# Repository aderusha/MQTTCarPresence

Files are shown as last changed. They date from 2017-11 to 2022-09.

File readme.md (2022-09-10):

# MQTTCarPresense

This project utilizes a [WeMos D1 mini Pro](https://wiki.wemos.cc/products:d1:d1_mini_pro), u.FL to SMA antenna whip, and an external antenna in a 3D-printed enclosure to indicate presense when powered on and attached to MQTT.

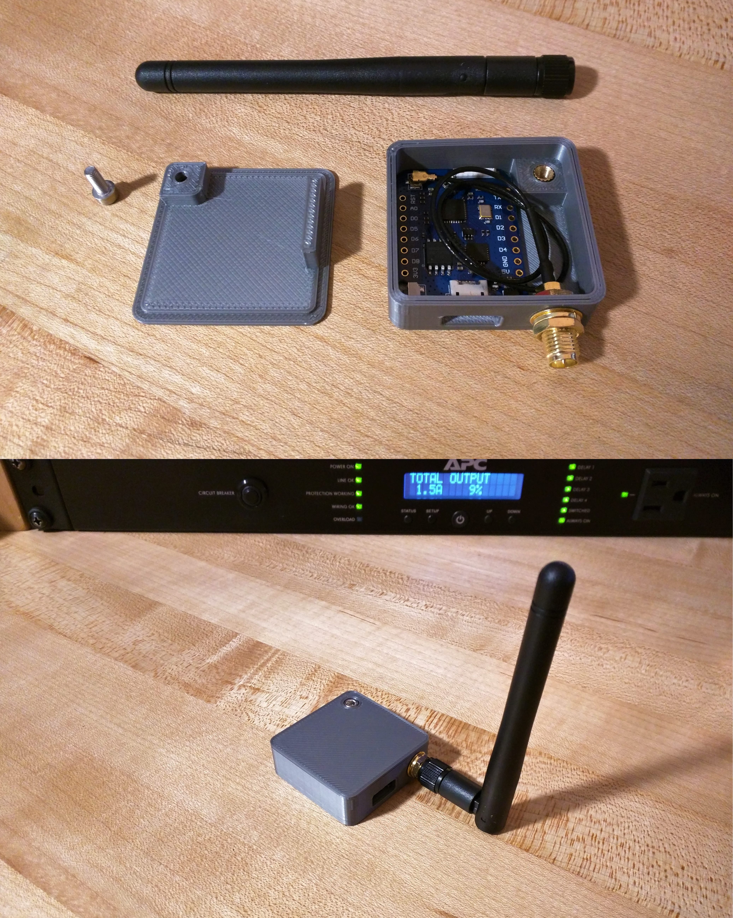
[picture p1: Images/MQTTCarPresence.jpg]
MQTTCarPresense


[The included Arduino code](/MQTTCarPresence) is setup to work with [Home Assistant MQTT Discovery](https://home-assistant.io/docs/mqtt/discovery/) to automatically create a `binary_sensor` device which will indicate the connection status of the device.  The device should be powered from your car's ignition so it's only on when the car is running.  When the device powers on, it will attempt to connect to the defined MQTT broker, publishes a discovery message, and configures a Last Will and Testament.  When the device is powered off (or you drive out of WiFi range), the Last Will and Testament is sent by your broker to update subscribed automation system(s).

[The included Home Assistant blueprint automation](MQTTCarPresence.yaml) example utilizes this information to open or close a connected garage door. Just copy the file url into the blueprint import menu and create an automation using the blueprint!



## Workflow - User perspective

* Car is in your garage and the garage door is closed
* You get in the car and turn it on, the garage door opens
* You drive away, the garage door closes a minute later
* When you arrive back home, the garage door opens as you approach
* When you turn off your car, the garage door closes about a minute later

## Detailed workflow

* Car is powered off, garage door is closed
* Car turns on, device publishes connection message to MQTT
* Home automation platform sees that the garage door is closed and the device is connected, then sends command to open garage
* You drive away when ready
* Device eventually drives out of range, dropping connection with the broker
* MQTT broker sends disconnection message configured as the LWT
* Home automation platform sees the garage door is open and the device has disconnected, then sends command to close garage
* You go on about your day, then return home.
* Device connects to WiFi, then MQTT and publishes connection message
* Home automation platform sees that the garage door is closed and the device is connected, then sends command to open garage
* You park your car and turn it off, dropping connection with the broker
* MQTT broker sends disconnection message configured as the LWT
* Home automation platform sees the garage door is open and the device has disconnected, then sends command to close garage

## Bill of Materials

* [WeMos D1 mini Pro](https://wiki.wemos.cc/products:d1:d1_mini_pro)
* u.FL to SMA antenna whip
* External 2.4GHz WiFi antenna
* M3x8mm socket head cap screw (or similar)
* M3x4x6 threaded insert (or similar)

## Arduino programming

The first order of business will be to setup the Arduino IDE to flash the provided Arduino sketch to the ESP8266.  [Download the IDE for your platform](https://www.arduino.cc/en/Main/Software) and [follow these instructions to add support for the ESP8266 platform](https://github.com/esp8266/Arduino#installing-with-boards-manager).

Next you will need to add the PubSubClient library for MQTT.  [Follow this guide for the general process](https://www.arduino.cc/en/Guide/Libraries) and add the 'PubSubClient' from the Library Manager.

[At the top of the Arduino sketch are several fields you must modify to fit your environment](https://github.com/aderusha/MQTTCarPresence/blob/master/MQTTCarPresence/MQTTCarPresence.ino#L3-L10) (WiFi details, MQTT broker IP, node name, etc).  Once those fields have been set you can upload to your microcontroller and monitor sensor status in Home Assistant.

> ## WARNING:
> 
> If you will be deploying more than one of these devices you **must** change the node names to be unique.  Failure to do so will result in a cascading series of MQTT connections/disconnections as your devices compete for access to your broker.

## WeMos D1 Mini Pro Antenna

In order to utilize an external antenna on the WeMos D1 Mini Pro, you will need to move a 0 ohm 0603 SMT resistor.  See [this blog post](http://raspi.tv/2017/how-to-use-external-antenna-on-wemos-d1-mini-pro-surface-mount-rework-video) along with [an accompanying video](https://www.youtube.com/watch?v=3lHoG1mu7hY&t=72) on how to make that happen.  A hot-air station will make this easier, but I was able to do this with a normal pencil iron.

## Tasmota Firmware Variant

If you are more familiar to Tasmota flashing and usage rather than Arduino Programming and building, this is another variant that you could use.  It will replace the **Arduino Programming** section above, but follows the guidelines of just about everything else.  The blueprint that is attached to this project named MQTT_Tasmota_CarPresence.yaml can be used as an alternate along with flashing the Di-Mini with Tasmota to accomplish the same thing as the original.  

This Tasmota Variant is set-up to work with [Home Assistant Tasmota Integration](https://www.home-assistant.io/integrations/tasmota/) to automatically create a `switch` which will indicate the connection status of the Car Presence Device.  It should show up as a switch with a name that matches the FriendlyName set-up in the Tasmota Web Console.

####    Follow these steps to flash the D1 Mini if using Tasmota: ####

* Flash the D1 Mini to the latest Tasmota version.
* Set up your WIFI, MQTT, Hostname, Friendly name, and all the normal stuff.  Details on the Tasmota homepage.
* Set the Device module to type `generic(18)`.
* Under configure module, 
    * set GPIO2 as LEDi 1
    * set GPIO4 as Button 1
    * set GPIO5 as Relay 1
* On the console, paste this to set-up the mcu functions as required for proper operation (Check Tasmota website for details on what these are):  
    * ```Backlog  SO19 0; SO56 1; SO63 1; SO65 1; WifiConfig 5```
* Go to Configure Other and be sure to set a Web Admin Password in case it goes into AP mode when you are away from Home.
* Set-up the blueprint `MQTT_Tasmota_CarPresence.yaml` similar to the instructions for the other blueprint above.



## Buy me a coffee

Buy me a coffee (https://www.buymeacoffee.com/gW5rPpsKR)

This project is powered by coffee.  [I might get a little weird about it at times](https://github.com/aderusha/RoastLearner), but it's not much of a stretch to suggest that coffee both powers and consumes a fair portion of my mental energy.  [Hook me up if you think HASP is cool](https://www.buymeacoffee.com/gW5rPpsKR).  Thanks!

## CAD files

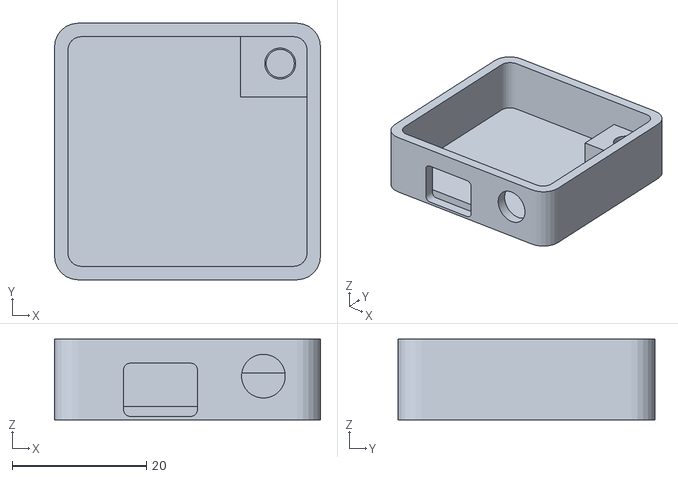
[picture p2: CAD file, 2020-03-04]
WeMos Pro Mini enclosure bottom.stl
39.6 x 38.2 x 12.0

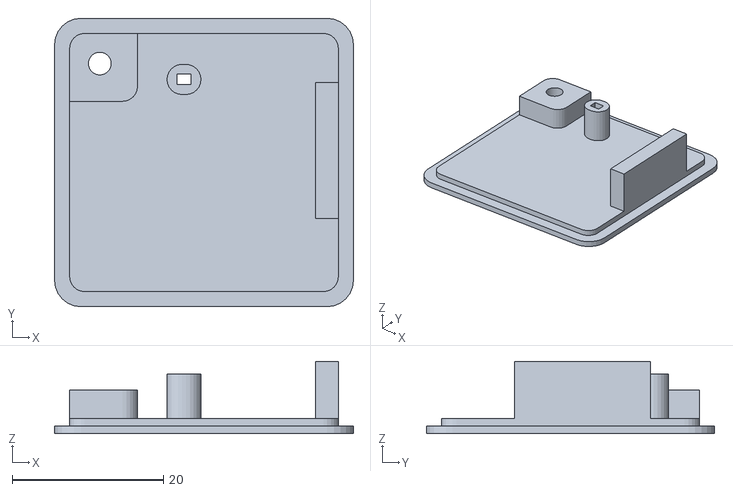
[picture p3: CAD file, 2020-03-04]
WeMos Pro Mini enclosure top.stl
39.6 x 38.2 x 9.60

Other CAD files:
WeMos Pro Mini enclosure.skp

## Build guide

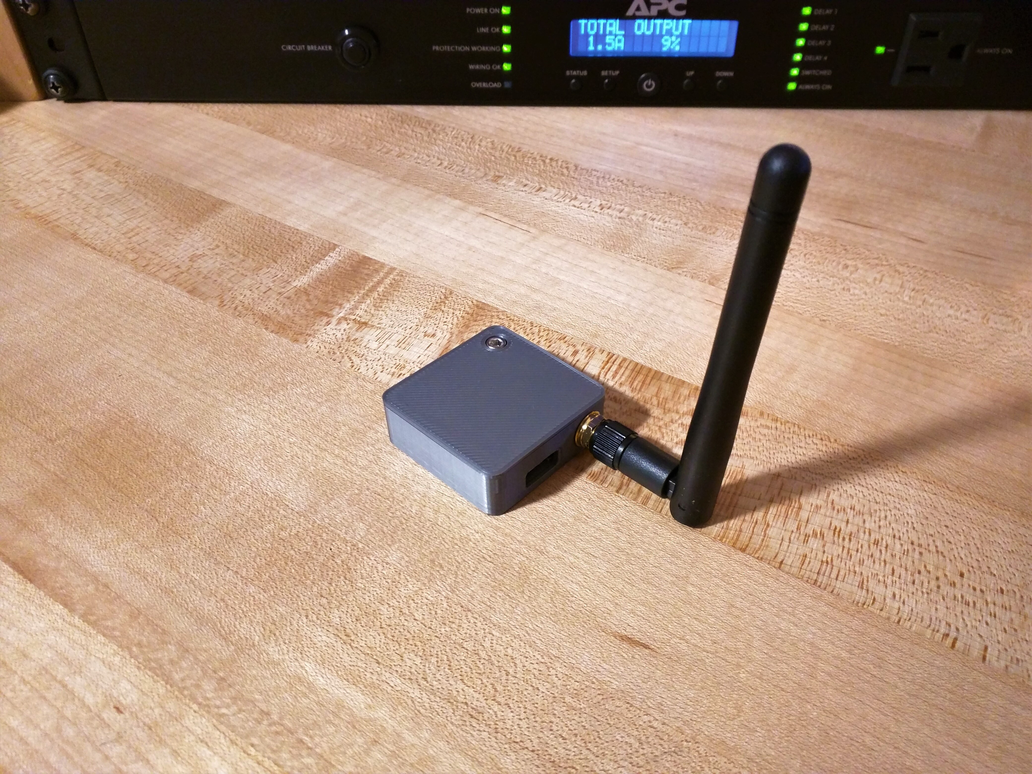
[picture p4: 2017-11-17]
Images/Assembled.jpg

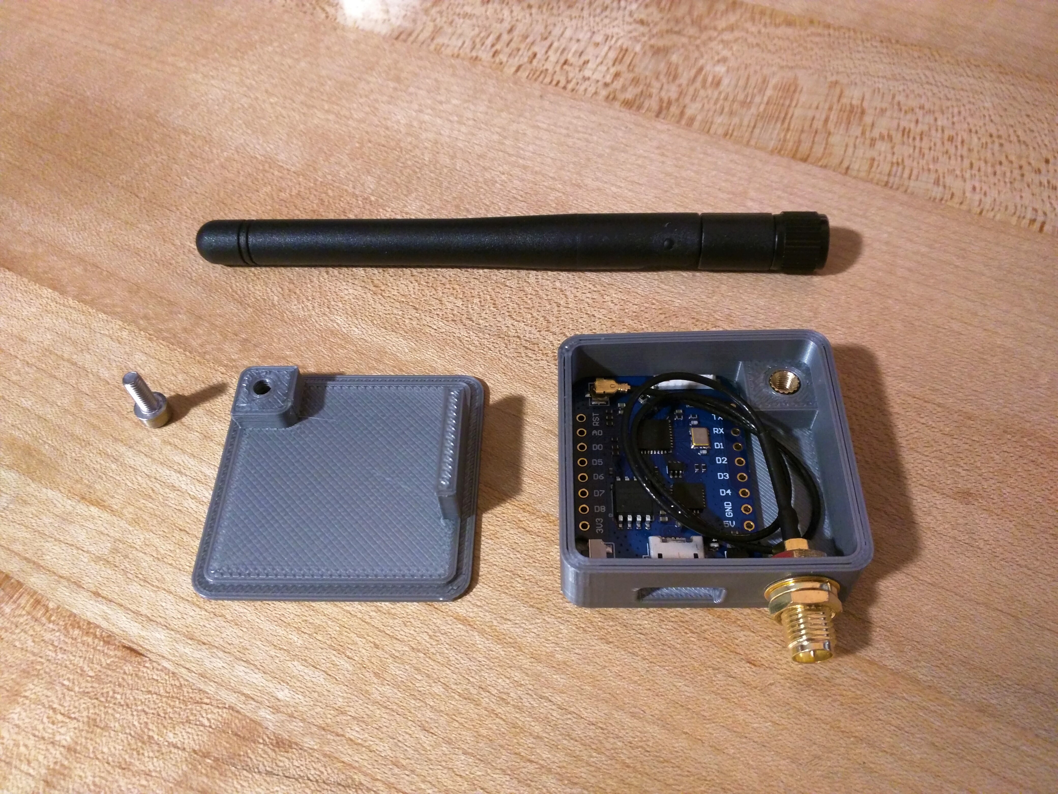
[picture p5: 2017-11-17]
Images/Disassembled.jpg

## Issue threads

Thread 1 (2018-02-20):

Will this work with D1 mini (non-pro)?

Snipercaine, 2018-02-20:
Hi,
Love this project.  I just tried it today and so far haven't been able to get it working.  I'm using a non-pro D1 mini.  I wouldn't expect that to be the problem.
I modified the values at the top of the sketch with my info. The max packet size is 512. The sketch loads up fine without any errors.
In Home Assistant I added the automation. Changed the entity_id to match the mqttNode (I assumed that was necessary, maybe it isn't).  When I power up the D1 mini, I don't see a new binary_sensor appear.
Most concerning is that when I plug the D1 into the computer, I don't see anything coming up in the Serial Monitor.

Any ideas of something else I can try?
Thanks!

aderusha, 2018-02-20:
This for sure will work on the non-pro mini (however the STL for the case may not work).  Serial for sure should be working @ 115200 8N1, so double check that the serial device is being created on your computer when plugging in the D1 mini and confirm you can get serial data to display.  From there you should be able to view debug messages regarding connection to WiFi and MQTT.  Next, use an MQTT client to make sure that the device is successfully publishing messages to your broker.  Finally, confirm that Home Assistant MQTT Discovery has been enabled in your `configuration.yaml` so that the `binary_sensor` device can be auto-created.

Snipercaine, 2018-02-21:
Thanks for the quick response!
I got it working.  I didn't have the mqtt discovery loaded.
I also did the automation in the automation editor.

I'd like to make a how-to video for this project.  I'll give you all the credit.
You can see the other stuff I've done here:  YouTube.com/c/DrZzs

Good work on this!  Genius idea!
Thanks
-Justin

ericflores, 2018-02-23:
As an alternative, I flashed Tasmota binary into the wemos using the flashing executable (Windows) that comes in the Espeasy zip file. Then configured following the instructions in the Tasmota wiki.
It is working perfectly.

Yet, I would like to capture uptime in minutes or seconds, and Tasmota only provides hours.

When I leave home I need the gate to close quickly after disconnecting, but when arriving I need some time to step out of the car and exit the garage thru the gate. I know that if the Wemos have been up more than 5 minutes is because I'm arriving. I could setup Homeassistant to behave differently when I'm leaving based on uptime.

ericflores, 2018-02-23:
Ohh, I had not even read your code. Your are reporting uptime in milliseconds! Looks like I'll have to compile and install your code!

edif30, 2018-05-03:
Will a NodeMCU board work?

1043717432, 2018-05-04:
Thanks for sharing

gorinie, 2018-05-20:
Hi
It is working form me with an ESP-01 and an USB adapter for ESP-01. This is very useful, you just plug it in the usb port on your car. No additional antenna but a Wemos d1 Mini with [(https://github.com/martin-ger/esp_wifi_repeater)] to repeat the signal nearby the Garage Door.  Also my automation in Home Assistant make use of a threshold on the signal with a binary_sensor, in such a way one can trim the closing of the Garage with [https://github.com/marthoc/GarHAge]  even before disconnection (this requires tuning...)

yaml code for Home Assistant
```
binary_sensor:
 - platform: threshold
    entity_id: sensor.yarissignal
    lower: -85.0
    name: yaris-threshold
    friendly_name: Yaris Threshold
    hysteresis: 0.0
```

regards,
Edoardo

1043717432, 2018-05-25:
@gorinie  Hi, Hello, thanks for sharing. What kind of esp-01 do you use with USB interface?

gorinie, 2018-05-25:
Hi,
I bought on amazon these:

https://www.amazon.it/AZDelivery-Adattatore-ESP-01-Modulo-Arduino/dp/B078J7LDLY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

Zoltant7, 2018-09-14:
This is  fun project, but i rather use HA with discovery feature so i only need my phone to detect that I'm home or not!

gorinie, 2018-09-14:
Did you try to convert your project in [esphomeyaml](https://esphomelib.com/esphomeyaml/) ? would be quite useful....

Closed 2020-01-15.

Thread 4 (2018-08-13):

Home Assistant not discovering D1 Mini Pro

FutureTense, 2018-08-13:
I’m using [this Aideepen WEMOS D1 Mini Pro - 16M Bytes External Antenna Connector ESP8266 WIFI IoT Board](https://www.amazon.com/dp/B07333L9VR/ref=cm_sw_r_cp_tai_WiqCBb5H7C2W1) but Home Assistant is not discovering it.  I know it’s connecting to my WiFi, because my router shows it and I can ping it.

What can I do to debug this?

aderusha, 2018-08-13:
Check to confirm that [Home Assistant MQTT Discovery](https://www.home-assistant.io/docs/mqtt/discovery/) is enabled, and try monitoring your MQTT broker messages using MQTT Lens (or similar) to make sure the device is sending messages.

neirbomn, 2019-01-16:
@aderusha,
I'm having considerable trouble getting this project to work. It's a fabulous idea and if I can get it to work it will be even better!

The binary_sensor 'CarPresence' and uptime and signal sensors are being created so MQTT discovery is definitely on.
I've also used MQTT Lens to check topics are being sent. They are as shown by a power cycle of the Wemos D1 Mini Pro in the screenshot below but I think my automation or HomeAssistant is where the problem lies for me.
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
In HomeAssistant, the binary sensor is shown all in lower case in the states section of the UI.
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

I altered the automations.yaml file entry for this but it doesn't seem to work. Any ideas appreciated - I've just about given up for the time being as I've spent 3 days trying to get it to work.

I have tried renaming the mqttNode in lowercase, this appears to either cause a conflict and the binary_sensor is repeatedly kicked off the MQTT server, setting the binary_sensor to OFF, it then reconnects which causes the binary_sensor to be set to ON and so on... I think this is if the 'CarPresence' binary_sensor is still in the config or if I send empty payloads and remove the 'CarPresence' sensors, update and reflash the WEMOS and also clear out MosQuiTTo's db and I check for the topic "homeassistant/binary_sensor/carpresence/state" then nothing is sent.

Is there anything you can think of checking or suggest?

aderusha, 2019-01-16:
Can you share your automation?

Closed 2020-01-15.

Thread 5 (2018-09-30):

New Binary sensor not being created

madzur, 2018-09-30:
Hello Aderusha and all. I love this idea and would really like to get this one working. I saw Dr. ZzS video and write up, which led me to this Github page.
I followed Aderusha's instructions with some help from Dr. ZzS more detailed steps and managed to set up Home assistant MQTT discovery and load Aderusha's sketch onto a D1 mini. The trouble starts when I plug the D1 mini into power and it connects to my wifi. I can see it in HA MQTT log as connected, however it is not adding itself as a binary sensor to configuration.yaml

> 1538340853: New connection from 192.168.1.160 on port 1883.
1538340853: New client connected from 192.168.1.160 as CarPresence (c1, k15, u'').

Specifically, in Dr. ZzS writeup (here: http://drzzs.com/mqtt-car-presence/) I’m stuck at the following step:

> After that, restart Home Assistant and plug in your D1 Mini. After a few seconds the blue LED will start flashing like crazy. This sketch is genius. It adds itself as an entity to Home Assistant.  Go to your states page and you should see a new “binary_sensor.CarPresence”.  Once you see that, you’re ready for the next step.

However the binary_sensor never shows up, either in configuration.yaml or in the states. Any tips on what I can do?

madzur, 2018-10-04:
I managed to get the serial monitor working and it is showing me the following output:
`
SDK:2.2.1(cfd48f3)/Core:2.4.2/lwIP:2.0.3(STABLE-2_0_3_RELEASE/glue:arduino-2.4.1-13-g163bb82)/BearSSL:6d1cefc

Hardware initialized, starting program load
Connecting to WiFi network: XXXXscandone
scandone
state: 0 -> 2 (b0)
state: 2 -> 3 (0)
state: 3 -> 5 (10)
add 0
aid 7
cnt

connected with XXXX, channel 11
dhcp client start...
ip:192.168.1.160,mask:255.255.255.0,gw:192.168.1.1
.
WiFi connected successfully and assigned IP: 192.168.1.160
Initialization complete

Attempting MQTT connection to broker: 192.168.1.101
MQTT discovery connectivity config: [homeassistant/binary_sensor/CarPresence/config] : [{"name": "CarPresence", "device_class": "connectivity", "state_topic": "homeassistant/binary_sensor/CarPresence/state"}]
MQTT discovery connectivity state: [homeassistant/binary_sensor/CarPresence/state] : [ON]
MQTT discovery signal config: [homeassistant/sensor/CarPresence-signal/config] : [{"name": "CarPresence-signal", "state_topic": "homeassistant/sensor/CarPresence-signal/state", "unit_of_measurement": "dBm", "value_template": "{{ value }}"}]
MQTT discovery signal state: [homeassistant/sensor/CarPresence-signal/state] : -56
MQTT discovery uptime config: [homeassistant/sensor/CarPresence-uptime/config] : [{"name": "CarPresence-uptime", "state_topic": "homeassistant/sensor/CarPresence-uptime/state", "unit_of_measurement": "msec", "value_template": "{{ value }}"}]
MQTT discovery uptime state: [homeassistant/sensor/CarPresence-uptime/state] : 20831
MQTT connected
pm open,type:2 0`

Still, when I check the states item in Home assistant, no new binary sensors appear. I’m out of my depth here, so any tips would be greatly appreciated.

aderusha, 2018-10-12:
Excellent, thanks for posting and tracking this down!

Closed 2018-10-12.

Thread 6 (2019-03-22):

Use this without the HASS automatic detection

Hyukishi, 2019-03-22:
Is there any chance you could rewrite a portion of this that would NOT utilize the automatic discovery of HASS? I want to be able to test the MQTT functionality without having to rely on HASS to pick up the device in order to be used and simply using the MQTT broker, in my case mosquitto, instead.

Villhellm, 2019-03-22:
You can subscribe to the topics manually as well. The topics are all listed in the ino file.

aderusha, 2019-03-23:
@Villhellm has it correct - the auto discovery is just there to help if you want to use it, there's nothing saying you must do so.  If you want to manually create an MQTT sensor, or use this with OpenHAB, or whatever else you're looking to do, you can do so without modifying any code in this project.  Just watch the MQTT messages, and configure your automations to react as needed.

Hyukishi, 2019-03-23:
Thanks to both of you. Have a good weekend!

Closed 2019-03-23.

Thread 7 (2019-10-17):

Wemos D1 Mini Pro - Failed to connect to ESP8266

biiiink, 2019-10-17:
I get this error when trying to upload this sketch to a D1 Mini Pro:

`Arduino: 1.8.10 (Mac OS X), Board: "LOLIN(WEMOS) D1 mini Pro, 80 MHz, Flash, Disabled, All SSL ciphers (most compatible), 16M (15M SPIFFS), v2 Lower Memory, Disabled, None, Only Sketch, 115200"

Sketch uses 312248 bytes (29%) of program storage space. Maximum is 1044464 bytes.
Global variables use 29952 bytes (36%) of dynamic memory, leaving 51968 bytes for local variables. Maximum is 81920 bytes.
esptool.py v2.6
2.6
esptool.py v2.6
Serial port /dev/cu.usbserial-01849A42
Connecting........_____....._____....._____....._____....._____....._____.....____Traceback (most recent call last):
  File "/Users/biiiink/Library/Arduino15/packages/esp8266/hardware/esp8266/2.5.2/tools/upload.py", line 25, in <module>
    esptool.main(fakeargs)
  File "/Users/biiiink/Library/Arduino15/packages/esp8266/hardware/esp8266/2.5.2/tools/esptool/esptool.py", line 2653, in main
    esp.connect(args.before)
  File "/Users/biiiink/Library/Arduino15/packages/esp8266/hardware/esp8266/2.5.2/tools/esptool/esptool.py", line 468, in connect
    raise FatalError('Failed to connect to %s: %s' % (self.CHIP_NAME, last_error))
esptool.FatalError: Failed to connect to ESP8266: Timed out waiting for packet header
esptool.FatalError: Failed to connect to ESP8266: Timed out waiting for packet header`

I have tried using a D1 Mini and it worked fine.  I've also tried a different D1 Mini Pro
These are the settings im using for the D1 Mini Pro
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

Any help would be greatly appreciated

aderusha, 2019-10-17:
This error is related to the communication between your Mac and the serial interface on your WeMos D1 Mini Pro.  It could be a bad board, bad cabling, or software configuration.  You might want to check [the issues list for esptool](https://github.com/espressif/esptool/issues) for further troubleshooting help.

Closed 2020-01-15.

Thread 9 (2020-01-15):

MQTT Retain

broyuken, 2020-01-15:
Hello,

I have this set up and working and LOVE it, it works great. The only issue I have is that when I restart HA the sensor state goes into unknown until I start the car again. How would I go about setting the retain flag or similar to make HA remember its last state upon a restart?

aderusha, 2020-01-15:
If you check out lines [152-157](https://github.com/aderusha/MQTTCarPresence/blob/master/MQTTCarPresence/MQTTCarPresence.ino#L152-L157) you'll find a group of commands to publish configuration and state to MQTT.  [The publish() function](https://pubsubclient.knolleary.net/api.html#publish2) accepts an optional third parameter for setting the retain flag.  Add a `, true` to the end of the function calls which don't already have that, and those additional published messages will also be retained.

broyuken, 2020-01-23:
Finally got a chance to try it, it worked perfect! Thank you

broyuken, 2020-01-23:
One thing I've noticed is that throughout the day when the car is off, the RSSI signal strength changes significantly. Any idea why this might be happening? The car is sitting in the garage off and it goes from -50 to -70. This throws off my card that shows if the car is in the garage or if it's away,

aderusha, 2020-01-23:
It's simply reporting the value provided to it by the ESP8266.  You're talking about a radio that was sold for a dollar, so adjust your expectations about the stability of that number accordingly.

If you wanted, one could possibly add a filtering library to smooth out the values over time with the hope of possibly removing noise from the signal.  This might be a good starting point: https://github.com/denyssene/SimpleKalmanFilter

broyuken, 2020-01-24:
That’s not what I’m talking about though. If I pull into my garage at 9am, and the RSSI is -50. I shut the car off and don’t get in it again that day. Around 11 or 12 the RSSI changes to -70. Note that the ESP has not turned on since 9am. This only started occurring since I enabled the retain flag on those 3 lines.

aderusha, 2020-01-24:
In that case something is publishing that value.  Try logging MQTT messages on your broker and see if you can't find what sent that value over.

broyuken, 2020-01-24:
Ok, I'll try to check my mosquitto logs

broyuken, 2020-02-18:
I checked mqtt explorer and it's retaining a value of -44 even though when my wife left for work this morning it had a value of -78. So when I restart HA it thinks my car is in the garage, when in fact it's gone. Something about the message isn't being retained correctly, any ideas? Either it's not updating to a new retained value or something.

aderusha, 2020-02-18:
Is there any chance one or more devices might have retain on, while another doesn't?  This should be trackable if you leave MQTT Explorer running and check the message history.

broyuken, 2020-02-18:
I'm not sure I follow, I have 2 cars I track with this, one has retain on (Odyssey), the other one I haven't updated yet (Murano). I wanted to fix this one first. Both devices have separate names, so they should be 2 separate entities.

aderusha, 2020-02-18:
Just throwing out ideas as to what might be happening there on your network, thought being maybe you have two devices publishing on the same topic but one of them isn't retaining for whatever reason.

I'd recommend keeping a copy of MQTT Explorer open (or similar), and using that to try and catch the problem in the act.  Those messages are there because something sent them, so it seems like the next step is to try and figure out what that was and then why.

broyuken, 2020-02-18:
So my wife just got home, the signal was set to -49, I restarted HA and now it's set to-64. However mqtt explorer is still showing -49. No idea where it's getting these numbers from.

kbweathe, 2020-03-03:
I just completed this project.  How can I make my garage door close as soon as I turn off the ignition. I have checked my automation in HA and I don't have a delay set.  Is the delay in the last will and testament?  If so how do I change it.  Help would be appreciated.

aderusha, 2020-03-03:
The LWT timeout is set by the "keepalive" value, which you can change in the pubsubclient.h file.  You can find details about this [here](https://github.com/knolleary/pubsubclient#limitations) and you can see the `#define` for that [here](https://github.com/knolleary/pubsubclient/blob/master/src/PubSubClient.h#L31).

Setting this value below 15sec is probably a bad idea, but that's where you'd do it.

kbweathe, 2020-03-03:
Allen,
I found the file but will take your advice and leave it at 15 sec.  Thanks so much for your help and quick response!  I have wanted to do this for 20+ years.  I also have a sliding gate that I am controlling with your project. I would like to send you some money for a couple of coffees, Cokes, or what ever you do. Can I do that for you? PayPal?  Let me know how and where, if you would accept it. I thank the good Lord for smart people like you so willing to share and help!
Brent 

    On Tuesday, March 3, 2020, 7:26:08 AM CST, Allen Derusha <notifications@github.com> wrote:

The LWT timeout is set by the "keepalive" value, which you can change in the pubsubclient.h file. You can find details about this here and you can see the #define for that here.

Setting this value below 15sec is probably a bad idea, but that's where you'd do it.

—
You are receiving this because you commented.
Reply to this email directly, view it on GitHub, or unsubscribe.

aderusha, 2020-03-04:
> Allen, I found the file but will take your advice and leave it at 15 sec.  Thanks so much for your help and quick response! 

You're welcome!

> I have wanted to do this for 20+ years.  I also have a sliding gate that I am controlling with your project. I would like to send you some money for a couple of coffees, Cokes, or what ever you do. Can I do that for you? PayPal?  Let me know how and where, if you would accept it.

I've added my [Buy Me a Coffee link](https://www.buymeacoffee.com/gW5rPpsKR) to the project page, thanks in advance for the consideration, I really appreciate it!

broyuken, 2020-08-18:
Curious, what is the reason against changing this setting? Would it just be if the car loses wifi while backing in the door could start closing on the roof? I was thinking of changing it to 5 seconds, wondering if this would be a fairly safe compromise?

aderusha, 2020-08-18:
That, and also because WiFi can be spotty, particularly when there is a $1 device with a PCB antenna involved.  So if for whatever reason it goes offline for a few seconds, just the time for the reconnect alone will trip over your 5 second window.  Leave some room for error, particularly when dealing with large mechanical systems.

broyuken, 2020-08-18:
I didn't even think of the time to boot, that makes a lot of sense. I will keep it at 15 seconds, thanks.

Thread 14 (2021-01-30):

Question disconnect time

03397, 2021-01-30:
Is there a way to make the displayed as disconnected earlier?

It takes sometime after I am disconnected from the wifi network to turn the binary sensor to off.

It does not happen the same when I am connected.

aderusha, 2021-01-30:
The keepalive interval is 10 seconds and should result in something around 30-60 seconds before the system knows the device is offline.  You don't want that number much lower because any intermittent dropped packets can result in the door trying to close on top of your car.

03397, 2021-01-30:
Is this configurable on the code?
To be honest with you I could not find it.

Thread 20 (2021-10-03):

Tasmota Variant won't work if relay is turned off.

SirGoodenough, 2021-10-03:
If you watched the DrZzs stream today, we found a bug in the Tasmota code...
I didn't find this in testing or think of it, but the relay needs to be ON for this to work correctly.
It monitors the switch for ON or unavailable...
Just need to add this to the config on the car D1 Mini.  I can't fix the repo until i get back home because my GitHub editing computer is there, but add this to the car's Tasmota set-up and it will always be started up in the on state when the device turns on.
```text
PowerOnState 1
so63 1
```
I will be able to update this at the end of October, until then, this is a note to make sure this problem gets fixed.

I will be happy to fix it then.

In the mean time, leave the relay set to on and it will continue to work as shown in the repo.

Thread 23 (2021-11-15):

Can the Arduino code be changed over the air?

VictorMFCoelho, 2021-11-15:
Hi!
My D1 Mini is on a hard to reach spot, can it be accessed over the air?
I have to make changes on two devices, one I have to clear the credencials as the car will be sold and the other a have to change the node name. Can it be done over the air?
Thanks!

aderusha, 2021-11-15:
Kinda yes but probably no.  If you compiled the code yourself and set the [otaPassword](https://github.com/aderusha/MQTTCarPresence/blob/master/MQTTCarPresence/MQTTCarPresence.ino#L5), then yes you can use the arduino Over-The-Air flash update mechanism to flash the device.  If you didn't set this value at compile time, you'll need physical access to the device.

VictorMFCoelho, 2021-11-15:
Thanks a lot!

Closed 2021-11-15.

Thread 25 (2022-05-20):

Wifi not working

Gurgeh88, 2022-05-20:
Hi there,

I've followed the steps in the readme and double checked the wifi settings that I entered into the sketch but after I've finished setting everything up and get to the stage for testing, nothing happens.

The LED does not blink like crazy, I can't ping the device from a local computer (destination host unreachable) and no new entity shows up in Home Assistant. I know the MAC address of the board so I have assigned it an IP in my router. Using the MQTTCarPresence sketch, it's not showing up as connected at all.

I double checked that the board was actually working on Wifi OK using another sketch and was able to successfully ping the device using this so it's not the board: https://techtutorialsx.com/2017/06/29/esp32-arduino-getting-started-with-wifi/

When compiling and uploading using ArduinoIDE, I don't receive any errors.

Please advise on how I can resolve this issue as I'd really like to give this project a go, it looks great! If you need any extra info, just let me know :)

Many thanks

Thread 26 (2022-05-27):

MQTT autodiscovery

Bluhme1, 2022-05-27:
Hi Thanks for your great work

The car presence module isn't shown in the Mosquito integration.
I get data into MQTT. I can see data in MQTT Explorer, so everything is working ok.

But why can't I see this module in the auto discovered list on Mosquito

/Lars

audioeptesicus, 2022-12-27:
I'm in the same position now.  I am not able to get HA to see the sensors, as auto discover does not seem to find them.

sledzik1984, 2022-12-28:
Same here

broyuken, 2023-04-03:
if its not finding it, just be aware that it doesn't show up as a device, just entities.

requiem240sx, 2023-06-01:
So Mosquitto has the data, home assistant runs on a different IP.  It doesn't add entities for me in home assistant... I was able to manually add some entities with these configs in my configuration.yaml file... but the blueprint doesn't work with them so I'm assuming I added them incorrectly.  I suppose I could make my own automation at this point, but the behavior seems off, as it only goes on/off as I connect to the MQTT server, I feel like it should be getting other data here.

```
mqtt:
  binary_sensor:
    - name: "Bike MQTT Connectivity"
      state_topic: "motorcycle/binary_sensor/BikePresence/state"
  sensor:
    - name: "Bike Wifi Signal Strength"
      state_topic: "motorcycle/sensor/BikePresence-signal/state"
      unit_of_measurement: "dBm"
      value_template: "{{ value }}"
    - name: "Bike Device Uptime"
      state_topic: "motorcycle/sensor/BikePresence-uptime/state"
      unit_of_measurement: "ms"
      value_template: "{{ value }}"
```

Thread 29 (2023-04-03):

Tasmota Setup

broyuken, 2023-04-03:
I'm trying to get this set up, and it sorta works, but I think it could be done better but I haven't been able to wrap my head around how LWT and Retain works with Tasmota. I use the signal sensor to determine if my car is in the garage, driveway or away and this doesn't work if its unavailable. Do you know of a way to make the tasmota sensor not go unavailable when the car is off and the esp is powered off? Ideally it would show the switch as off as the LWT and the sensor data would be retained. Also I would like to be able to set the keepalive to something shorter as I like to have the delay set in my automation so the door shuts if the switch is off for 15 seconds instead of having the timeout set on the esp8266 itself.

The main reason I'm trying to use tasmota is because
1. the arduino method doesn't create a device in HA and
2. This is the only arduino code I use, and would like to consolidate everything in Tasmota or ESPHome for my dev boards.

broyuken, 2023-04-10:
@aderusha Hello, do you know if this is possible?

aderusha, 2023-04-11:
Sorry man, the Tasmota stuff came from a user contribution and I don't use that part of the codebase.  I'd suggest hitting up the Tastmota folks to see if there's a way to make their firmware work in that way.  Wish I had a better answer my friend.

broyuken, 2023-04-11:
All good, this component is awesome as it is. Are there any plans to update it to actually create a device in home assistant as opposed to just entities? If so I’d probably just continue using the arduino code.

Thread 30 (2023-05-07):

nodemcu 32s

asucrews, 2023-05-07:
Hello, do you know if anyone has converted this to esp32 based or if it is even possible?

guy0nabuffalo, 2024-03-07:
Hi I recently used chatgpt to convert the code to ESP32. You can find it here https://github.com/guy0nabuffalo/ESP32-MQTTCarPresence

asucrews, 2024-03-09:
Cool, I check this out this weekend

guy0nabuffalo, 2024-03-13:
Let me know how it goes.
Today I put the code on a [ESP32-WROOM-32U](https://www.amazon.com/HiLetgo-ESP32-DevKitC-ESP32-WROOM-32U-ESP-WROOM-32U-Development/dp/B09KLS2YB3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) which uses an [external antenna](https://www.amazon.com/Antenna-Pigtail-Wireless-Routers-Repeater/dp/B07R21LN5P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). Seems to be working well. Range is better than an ESP32 with the onboard antenna.

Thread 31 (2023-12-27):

Confirmation of expected behavior: do nothing if state is already matching desired state

xanderphillips, 2023-12-27:
My garage doors will close on their own using the timer in the 'smart' opener from the manuf.
I have ratgdo setup to provide state and control to HA.  Can someone confirm if the blueprint automation is smart enough to not try to close an already closed door?  I am guessing by the way the logic looks to my untrained eyes that it should ignore trying to close an already closed door, but I'd like a second opinion.

I guess same would go for not trying to open an already open door.

aderusha, 2023-12-27:
This probably doesn't require two issues :D

The "delay" is entirely handled by your cover device.  For example, the blueprint here calls "cover.open" if the device has come online and the door is currently "closed".  A cover can be "open" or "opening" or "closed" or "closing" (or a percentage if supported).  How your cover progresses through those stages is up to whatever integration is handling your door and is outside of the scope or control of the blueprint here.

xanderphillips, 2023-12-27:
That's the confirmation I was looking for, that it looks at the current state, and not just blindly sending an open if it's already open or a close if it's already closed, as I believe my door would toggle instead of honoring the actual command. I need to test that actually!  Thanks for the quick response!

Closed 2023-12-27.

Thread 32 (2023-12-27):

Is there a timer that sets the minimum close door delay?

xanderphillips, 2023-12-27:
I skimmed the .ino code as well as the yaml file and don't see a close delay programmed into the logic.

For my setup the processing time of the MQTT messages seems to result in about a 1.5 min lag, which is pretty good, but wanted to know if there was a setting somewhere I didn't see that would allow extending it for people that wanted a longer window of time.

aderusha, 2023-12-27:
duplicate of https://github.com/aderusha/MQTTCarPresence/issues/31

Closed 2023-12-27.

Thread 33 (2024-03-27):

How can I add additional conditions to the initial car start up 'open garage'?

NZ3-14, 2024-03-27:
Hi,

Love the solution - Thanks for making it available!

I'm new to HA and moving from Homeseer.

How can I add two additional conditions to the initial car starting-up sequence?

1—Test that a light is on in the garage (I have a motion-activated light in the garage). This will confirm that I am in the garage, as the car wakes up at times to report its state of charge, and this wake-up activates the USB port.

2- Test that the car is in the garage (open-garage distance sensor) as the car is often left on the driveway and is driven away.

Huge thanks for any assistance!

Philip

aderusha, 2024-03-27:
You'd have to write your own automations for that, but you can use the code presented in the blueprint to get you started.  Should all be pretty reasonable to make happen, the blueprint itself doesn't do all that much and should be easy to re-create and then add to using the HA automation editor.

NZ3-14, 2024-03-30:
Thanks - Can you please let me know at which line I should add the conditions to limit the opening hours?

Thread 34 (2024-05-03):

MQTT unique_id / Device

xanderphillips, 2024-05-03:
How can we get the devices to show up as Devices instead of just multiple Entities and also have them published with unique_id values such that HA doesn't complain about them not being unique?

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

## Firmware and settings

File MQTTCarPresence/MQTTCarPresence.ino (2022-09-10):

////////////////////////////////////////////////////////////////////////////////////////////////////
// Modify these values for your environment
const char *wifiSSID = "wifissid";                  // Your WiFi network name
const char *wifiPassword = "wifipassword";          // Your WiFi network password
const char *otaPassword = "";                       // OTA update password
const char *mqttServer = "hassio.local";            // Your MQTT server IP address
const char *mqttUser = "";                          // mqtt username, set to "" for no user
const char *mqttPassword = "";                      // mqtt password, set to "" for no password
const String mqttNode = "CarPresence";              // Your unique hostname for this device
const String mqttDiscoveryPrefix = "homeassistant"; // Home Assistant MQTT Discovery, see https://home-assistant.io/docs/mqtt/discovery/
////////////////////////////////////////////////////////////////////////////////////////////////////

// Home Assistant MQTT Discovery, see https://home-assistant.io/docs/mqtt/discovery/
// We'll create one binary_sensor device to track MQTT connectivity
const String mqttDiscoBinaryStateTopic = mqttDiscoveryPrefix + "/binary_sensor/" + mqttNode + "/state";
const String mqttDiscoBinaryConfigTopic = mqttDiscoveryPrefix + "/binary_sensor/" + mqttNode + "/config";
// And a sensor for WiFi signal strength
const String mqttDiscoSignalStateTopic = mqttDiscoveryPrefix + "/sensor/" + mqttNode + "-signal/state";
const String mqttDiscoSignalConfigTopic = mqttDiscoveryPrefix + "/sensor/" + mqttNode + "-signal/config";
// And a sensor for device uptime
const String mqttDiscoUptimeStateTopic = mqttDiscoveryPrefix + "/sensor/" + mqttNode + "-uptime/state";
const String mqttDiscoUptimeConfigTopic = mqttDiscoveryPrefix + "/sensor/" + mqttNode + "-uptime/config";

const String mqttDiscoBinaryConfigPayload = "{\"name\": \"" + mqttNode + "\", \"device_class\": \"connectivity\", \"state_topic\": \"" + mqttDiscoBinaryStateTopic + "\"}";
const String mqttDiscoSignalConfigPayload = "{\"name\": \"" + mqttNode + "-signal\", \"state_topic\": \"" + mqttDiscoSignalStateTopic + "\", \"unit_of_measurement\": \"dBm\", \"value_template\": \"{{ value }}\"}";
const String mqttDiscoUptimeConfigPayload = "{\"name\": \"" + mqttNode + "-uptime\", \"state_topic\": \"" + mqttDiscoUptimeStateTopic + "\", \"unit_of_measurement\": \"msec\", \"value_template\": \"{{ value }}\"}";

// Set the signal strength and uptime reporting interval in milliseconds
const unsigned long reportInterval = 5000;
unsigned long reportTimer = millis();

// Set LED "twinkle" time for maximum daylight visibility
const unsigned long twinkleInterval = 50;
unsigned long twinkleTimer = millis();

#include <ESP8266WiFi.h>
#include <ESP8266mDNS.h>
#include <WiFiUdp.h>
#include <ArduinoOTA.h>
#include <PubSubClient.h>

WiFiClient wifiClient;
PubSubClient mqttClient(wifiClient);

////////////////////////////////////////////////////////////////////////////////////////////////////
// System setup
void setup()
{
  pinMode(LED_BUILTIN, OUTPUT);
  digitalWrite(LED_BUILTIN, HIGH);
  Serial.begin(115200);

  Serial.println("\nHardware initialized, starting program load");

  // Start up networking
  setupWifi();

  // Create server and assign callbacks for MQTT
  mqttClient.setServer(mqttServer, 1883);
  mqttClient.setCallback(mqtt_callback);

// The string payloads spill over the default MAX_PACKET_SIZE 128.
  mqttClient.setBufferSize(512);

  mqttConnect();

  // Start up OTA
  if (otaPassword[0])
  {
    setupOTA();
  }

  Serial.println("Initialization complete\n");
}

////////////////////////////////////////////////////////////////////////////////////////////////////
// Main execution loop
void loop()
{
  // check WiFi connection
  if (WiFi.status() != WL_CONNECTED)
  {
    setupWifi();
  }

  // check MQTT connection
  if (!mqttClient.connected())
  {
    mqttConnect();
  }

  // MQTT client loop
  if (mqttClient.connected())
  {
    mqttClient.loop();
  }

  // LED twinkle
  if (mqttClient.connected() && ((millis() - twinkleTimer) >= twinkleInterval))
  {
    digitalWrite(LED_BUILTIN, !digitalRead(LED_BUILTIN));
    twinkleTimer = millis();
  }

  // Report signal strength and uptime
  if (mqttClient.connected() && ((millis() - reportTimer) >= reportInterval))
  {
    String signalStrength = String(WiFi.RSSI());
    String uptimeTimer = String(millis());
    mqttClient.publish(mqttDiscoSignalStateTopic.c_str(), signalStrength.c_str());
    mqttClient.publish(mqttDiscoUptimeStateTopic.c_str(), uptimeTimer.c_str());
    reportTimer = millis();
  }

  // OTA loop
  if (otaPassword[0])
  {
    ArduinoOTA.handle();
  }
}

////////////////////////////////////////////////////////////////////////////////////////////////////
// Functions

////////////////////////////////////////////////////////////////////////////////////////////////////
// Handle incoming commands from MQTT
void mqtt_callback(char *topic, byte *payload, unsigned int payloadLength)
{
}

////////////////////////////////////////////////////////////////////////////////////////////////////
// Connect to WiFi
void setupWifi()
{
  Serial.print("Connecting to WiFi network: " + String(wifiSSID));
  WiFi.hostname(mqttNode.c_str());
  WiFi.mode(WIFI_STA);
  WiFi.setSleepMode(WIFI_NONE_SLEEP);
  WiFi.begin(wifiSSID, wifiPassword);

  while (WiFi.status() != WL_CONNECTED)
  {
    delay(1);
  }
  Serial.println("\nWiFi connected successfully and assigned IP: " + WiFi.localIP().toString());
}

////////////////////////////////////////////////////////////////////////////////////////////////////
// MQTT connection and subscriptions
void mqttConnect()
{
  digitalWrite(LED_BUILTIN, HIGH);
  Serial.println("Attempting MQTT connection to broker: " + String(mqttServer));
  // Attempt to connect to broker, setting last will and testament
  if (mqttClient.connect(mqttNode.c_str(), mqttUser, mqttPassword, mqttDiscoBinaryStateTopic.c_str(), 1, 1, "OFF"))
  {
    // when connected, record signal strength and reset reporting timer
    String signalStrength = String(WiFi.RSSI());
    reportTimer = millis();
    String uptimeTimer = String(millis());
    // publish MQTT discovery topics and device state
    Serial.println("MQTT discovery connectivity config: [" + mqttDiscoBinaryConfigTopic + "] : [" + mqttDiscoBinaryConfigPayload + "]");
    Serial.println("MQTT discovery connectivity state: [" + mqttDiscoBinaryStateTopic + "] : [ON]");
    Serial.println("MQTT discovery signal config: [" + mqttDiscoSignalConfigTopic + "] : [" + mqttDiscoSignalConfigPayload + "]");
    Serial.println("MQTT discovery signal state: [" + mqttDiscoSignalStateTopic + "] : " + WiFi.RSSI());
    Serial.println("MQTT discovery uptime config: [" + mqttDiscoUptimeConfigTopic + "] : [" + mqttDiscoUptimeConfigPayload + "]");
    Serial.println("MQTT discovery uptime state: [" + mqttDiscoUptimeStateTopic + "] : " + uptimeTimer);
    mqttClient.publish(mqttDiscoUptimeConfigTopic.c_str(), mqttDiscoUptimeConfigPayload.c_str(), true);
    mqttClient.publish(mqttDiscoUptimeStateTopic.c_str(), uptimeTimer.c_str());
    mqttClient.publish(mqttDiscoBinaryConfigTopic.c_str(), mqttDiscoBinaryConfigPayload.c_str(), true);
    mqttClient.publish(mqttDiscoBinaryStateTopic.c_str(), "ON");
    mqttClient.publish(mqttDiscoSignalConfigTopic.c_str(), mqttDiscoSignalConfigPayload.c_str(), true);
    mqttClient.publish(mqttDiscoSignalStateTopic.c_str(), signalStrength.c_str());
    Serial.println("MQTT connected");
    digitalWrite(LED_BUILTIN, LOW);
  }
  else
  {
    Serial.println("MQTT connection failed, rc=" + String(mqttClient.state()));
  }
}

////////////////////////////////////////////////////////////////////////////////////////////////////
// (mostly) boilerplate OTA setup from library examples
void setupOTA()
{
  // Start up OTA
  // ArduinoOTA.setPort(8266); // Port defaults to 8266
  ArduinoOTA.setHostname(mqttNode.c_str());
  ArduinoOTA.setPassword(otaPassword);

  ArduinoOTA.onStart([]() {
    Serial.println("ESP OTA:  update start");
  });
  ArduinoOTA.onEnd([]() {
    Serial.println("ESP OTA:  update complete");
  });
  ArduinoOTA.onProgress([](unsigned int progress, unsigned int total) {
    //Serial.printf("Progress: %u%%\r", (progress / (total / 100)));
  });
  ArduinoOTA.onError([](ota_error_t error) {
    Serial.println("ESP OTA:  ERROR code " + String(error));
    if (error == OTA_AUTH_ERROR)
      Serial.println("ESP OTA:  ERROR - Auth Failed");
    else if (error == OTA_BEGIN_ERROR)
      Serial.println("ESP OTA:  ERROR - Begin Failed");
    else if (error == OTA_CONNECT_ERROR)
      Serial.println("ESP OTA:  ERROR - Connect Failed");
    else if (error == OTA_RECEIVE_ERROR)
      Serial.println("ESP OTA:  ERROR - Receive Failed");
    else if (error == OTA_END_ERROR)
      Serial.println("ESP OTA:  ERROR - End Failed");
  });
  ArduinoOTA.begin();
  Serial.println("ESP OTA:  Over the Air firmware update ready");
}

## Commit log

2017-11-17 Add Arduino sketch and update readme
2018-01-16 Add RSSI reporting
    Publish Home Assistant MQTT discovery packets to create a signal strength sensor and send signal readings while connected to the MQTT broker
    [MQTTCarPresence.ino]
2018-01-16 Documentation update
    Add details on enabling the external antenna for a WeMos D1 Mini Pro
2018-01-16 Add viewport for connectivity LED indicator
    [WeMos Pro Mini enclosure bottom.stl, WeMos Pro Mini enclosure top.stl, WeMos Pro Mini enclosure.skp]
2018-01-17 Improved fit for enclosure
    PLA top layers print just a touch over-size, prevnting a snug fit of the enclosure pieces. Modified to accomodate.
    [WeMos Pro Mini enclosure top.stl, WeMos Pro Mini enclosure.skp]
2018-01-17 LED Viewport adjustment
    [WeMos Pro Mini enclosure top.stl, WeMos Pro Mini enclosure.skp]
2018-01-17 Add uptime reporting and LED twinkle
2018-01-17 Fix sensor naming
2018-05-12 Dumb bug in sensor discovery string
    [MQTTCarPresence.ino]
2018-07-30 Update MQTTCarPresence.ino
    Line swap to update uptime values before on/off. This is to make it easier to detect if the car has just started up or if it is returning
    [MQTTCarPresence.ino]
2020-03-04 Fixed hidden surface in original model causing non-manifold STL
    [WeMos Pro Mini enclosure bottom.stl, WeMos Pro Mini enclosure top.stl, WeMos Pro Mini enclosure.skp]
2021-03-04 Add import blueprint button.
2021-05-26 Suggested update to use Tasmota instead of Arduino
    This adds a second blueprint and a paragraph in the README to give users the option of using Tasmota instead of collecting and building Arduino code.
    Think of it as a lower bar to spread this to more folks.
2021-08-07 Add the import link
    I loaded my Tasmota version of the bluepring into my GIST repo.
    I also created an import button.
    I wanted the import button to show here.
    I also shared my blueprint on the exchange and pointed tham all to the mother repo to figure out how to use it.
2022-01-16 Set MQTT buffer size from API
    There is no longer a need to edit to library.
    The `setBufferSize` function was added in
    [v2.8](https://github.com/knolleary/pubsubclient/releases/tag/v2.8).
    [MQTTCarPresence.ino]
2023-09-18 Fix minimum to work with filter entries.
